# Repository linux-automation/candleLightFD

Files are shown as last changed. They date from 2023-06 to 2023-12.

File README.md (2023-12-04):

# candleLight FD

candleLight FD is a modern, CAN-FD capable version of the 
[candleLight](https://github.com/linux-automation/candleLight/) based on a STM32G0B1 microcontroller.

Out of the box it comes with a single CAN channel placed.
But footprints for a second CAN channel are available.

The candleLight FD is - like the candleLight - licensed under the CERN OHL v1.2 open hardware license.

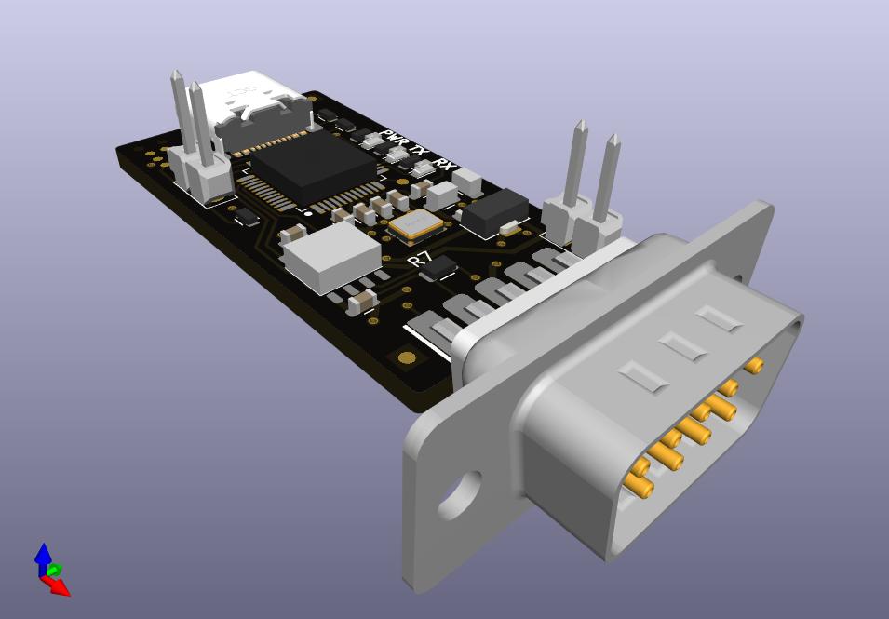
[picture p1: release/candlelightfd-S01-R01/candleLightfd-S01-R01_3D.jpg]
candleLight FD revision 1


## Where to get one

The candleLight FD is available from [Linux Automation](https://linux-automation.com)
as a SMD-assembled and functionally tested kit.

## Hardware

### Interfaces

The candleLight FD uses a USB-C (USB 2 only) connector to connect to your PC.

CAN is provided on the industry standard D-SUB9 pinout:

   * CAN1:
     * High: Pin 7
     * Low: Pin 2
   * CAN2:
     * High: Pin 8
     * Low: Pin 1
   * Power:
     * 12V: Pin 9 (can be provided via P1)
     * GND: Pin 3, Pin 6

### Releases: Revision 1

[Manufacturing Data](./release/candlelightfd-S01-R01) |
[Schematic](./release/candlelightfd-S01-R01/candlelightfd-S01-R01-V01/candlelightfd-S01-R01.pdf) |
[Interactive BOM](./release/candlelightfd-S01-R01/candlelightfd-S01-R01-V01/candlelightfd-S01-R01_BOM.html)

(This is the current release.)

Release Notes:

  * Initial release of the candleLight FD.

## Firmware

The firmware is based on the [candleLight_fw](https://github.com/candle-usb/candleLight_fw).
Select the board config `BOARD_candleLightFD` when building the firmware.

> **_NOTE_**: We are currently upstreaming our changes to the *candleLight_fw* repository.
> While doing so you can find our sources 
> [here](https://github.com/linux-automation/candleLight_fw/tree/topic/candleLightFD).

## Programming and Debugging

Everyday programming can be done via USB.
Simply invoke `dfu-util` while the device is running.
More information on flashing can be found in the
[firmware repository](https://github.com/candle-usb/candleLight_fw#flashing).

In case the device is bricked: Short the two pins labeled *BOOT* while powering on
the device.
The CPU will start in *serial download mode*.

For debugging a single wire interface is exposed on X3.
It can be connected using a [Tag Connect TC2030-IDC-NL](https://www.tag-connect.com/product/tc2030-idc-nl)
adapter.
The pinout is derived from the CandleLight.

The pinout is:

    * Pin 1: 3V3
    * Pin 2: SWCLK
    * Pin 3: GND
    * Pin 4: SWDIO
    * Pin 5: NRST
    * Pin 6: (not connected)

This picture shows X3 on the device.
X3 is the connector in the lower left corner - below the USB-C connector.

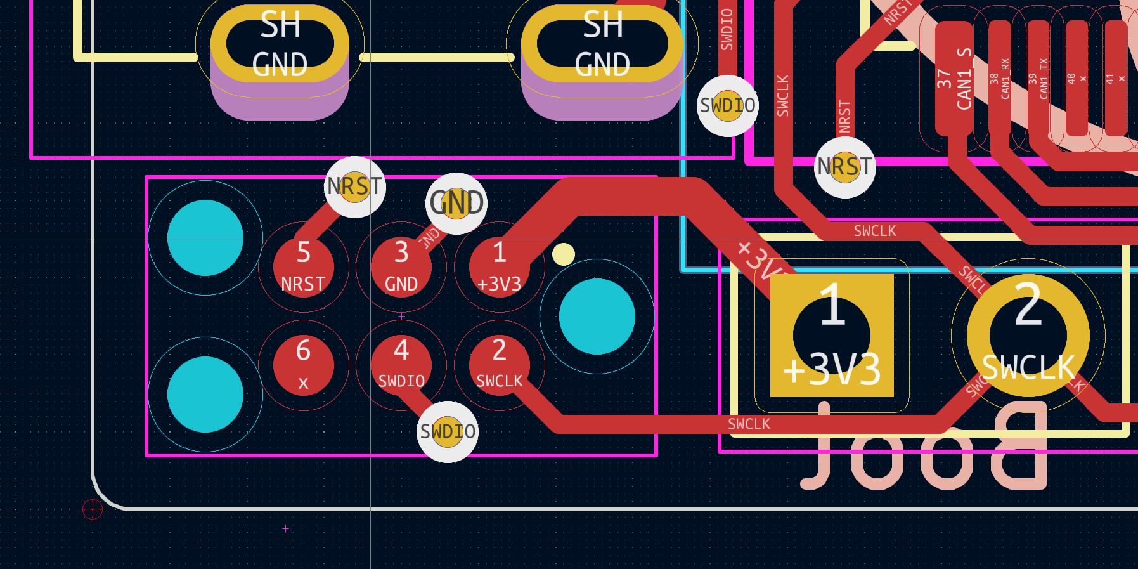
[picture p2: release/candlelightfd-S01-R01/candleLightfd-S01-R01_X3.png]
candleLight X3


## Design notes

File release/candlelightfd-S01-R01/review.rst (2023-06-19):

PCB / PCBA Review Checklists
============================

Schematic Related Topics
########################

Allgemeines
-----------

* [x] Braucht der Reset-Pin einen Pull-Up?
      Nein hat ein internen pullup von 40k.
* [x] Testpunkte für RX, TX, falls da genug Platz ist?

Drawing
-------

* [x] Are all sheets drawn with the same paper size? Is A4 used if possible?
* [x] Does the title block contain the name of the used git-repository?
* [x] Is the revision count in the title block up to date?
* [x] Are comments added where the schematic is not intuitive?

Nets and hierarchy
-------------------

* [x] Are all mayor nets named? (Either with a net label or due to the use of buses or hierarchical sheet entries.)
* [x] Are the directions of hierarchical sheet entries set in a meaningful way?

ERC
----

* [x] Does an ERC return errors? Are all severe error commented in the schematic?

Meta-Information
----------------

* [x] Do all symbols of manufacturer parts contain a "Manufacturer" and "MPN" field?
* [x] Are all libraries used from a local checkout of the kicad-ptx-lib or
      a projekt-local library? (Do not use absolute or system-wide paths.)

Electrical
----------

* [x] Do all Capacitors have a sufficient voltage derating applied?
      - Electrolyte Capacitors: U_R >= U_max * 1.3
      - Ceramic Capacitors:     U_R >= U_max * 1.5 .. 2
* [x] For all variants:
      * Are all necessary parts placed?
      * Are unnecessary parts not placed? (fit: none)
* [x] Are all analog devices (LDOs, OP-AMPs,...) within a stable operating region?
      * Check datasheet for stability region.
      * Check capacitive loads.
      * Check current to reference pins is sufficient
* [-] For designs including step-up/-down or flyback magnetics:
      are there footprints onto which snubber networks can be placed?
* [x] For designs containing digital high speed clock traces:
      are there footprints onto which filters can be placed?

PCB
####

General
-------

* [x] Does the PCB contain a PTXguin or a LAG rocket-penguin if the
      design is made for PTX or the LAG.
* [x] Does the PCB has a layer stackup in copper on every layer?
* [x] Is the PCB marked with the PCB number in copper on at least one side?
      Additional Marks in Mask or Silkscreen are possible.
      Marking must use variables to create the following names:
      * prefix
      * type_number
      * release
* [x] Does a DRC return no severe errors?
* [x] Are all libraries used from a local checkout of the kicad-ptx-lib or
      a projekt-local library? (Do not use absolute or system-wide paths.)
* [x] Have all changes been imported from the schematic?
* [x] Is the auxiliary origin reference point set to a corner of the PCB?
      Preferably on the metric grid.
      Preferably on the lower left corner of the PCB.

* [x] Is the layer stack in the drawing frame up to date?
      - All layers mentioned?
      - Copper thickness, impedances, finishes correct?

* [x] Are fiducials placed on all sides with SMD or THT components?
      Place at least 3 fiducials on each side.
      Does the fiducial match the manufacturers specifications?

* [-] Are planes split in a useful way?
      - Analog and digital parts are separated
      - High currents are directed away from sensitive circuits
      - Oscillators are placed on a GND-island
* [-] Are the reference planes of high-speed signals contiguous?
      Are planes AC-coupled where reference planes change?

* [-] Have impedance controlled traces been routed with the correct width/gap for the layer?
* [-] Is a definition of impedance controlled traces placed on a non-copper layer
      and is it up to date?

* [-] Are clearance and creepage requirements (for areas with high voltages)
      met?

Testing
#######

* [x] Is there a way to bring up the device at EOL or in maintenance?
      e.g. flash software, readout images, ...
      All signals needed to bring the device into non-normal
      boot-modes must be exposed to a connector or testpoint.
* [x] Is there a way to test all mayor functions at EOL?
* [-] Does the PCB have drillings for mounting on a testing rig?
* [-] Do all mayor nets have test points or vias without tenting?
* [-] Are all test points placed at least 2.54mm apart?

* [x] Are potentially noisy traces (e.g. unfiltered outputs of voltage
      regulators) only as wide as they have to be?
      Unnecessarily thick traces increase the coupling of noise onto
      planes and other traces.

Create release
##############

* [x] Have Vias been untented? (jma's KiCAD-plugin: https://gitlab.pengutronix.de/jma/kicad_plugins)
* [x] Have Planes been rebuilt? (use shortcut B in PCBNEW)

* [x] Change Status from Draft to Release
* [x] Create new folder in release
* [ ] Add release to release management (https://gitlab.pengutronix.de/hardware/release_management)

Manufacturing Data
##################

Directory structure is defined here:
  https://wiki.pengutronix.de/manual/devel/hardware/kicad-project.html

* [x] Call `release_generator.py <release_tag>`

* Assembly:
  * [x] Convert the -extended.bom.csv to .xlsx for manufacturing.

  * (-) Optional: List of BOM changes:
        * [-] Use tools/bom/bom_diff.sh prev-bom.csv cur-bom.csv | aha > bom-diff.html
              to generate a list of changes to the BOM between revisions.
        * [-] Sanity-Check the listed changes to the bom.

  * [x] Interactive HTML BOM:
        PCBNEW -> Interactive HTML BOM
        Settings:
        * Activate: "Incldue Tracks/zones"
        * Activate: "Include nets"

* PCB:
  * PCB Data as PDF:
    * Output into a directory like:
      ./release/name-S01-R01/name-P01-R01-V01/pdf/
    * PCBNEW -> File -> Plot
    * Settings:
      * Plot Format: Gerber
      * Active "Plot border and title block"
      * Deactivate "Exclude PCB edge from other layers"
      * Deactivate "Do not tent vias"
      * Activate "Check zone files before plotting"
      * Layers:
        * [x] Cu-Layers depending on Project
        * [x] Paste
        * [x] Silkscreen
        * [x] Mask
        * [x] Uwgs. User (if containing e.g. Size of PCB)
        * [x] Edge.Cuts
        * [x] Fab and CrtYrd -layer
  * 3D Render of PCB as JPG:
    * Output into a directory like:
      ./release/name-S01-R01/name-P01-R01-V01/
    * PCBNEW -> 3D-View -> File -> 'Export Current ciew as JPEG'
    * Settings:
      * Set Silk and Mask color according to layer stack
    * [x] One Render that shows the PCBA from TOP
    * [x] One Render that shows the PCBA from BOT
    * (x) Optionally: Renderings that show important details
  * [x] Test-Data for flying probe:
    * Output into a directory like:
      ./release/name-S01-R01/name-P01-R01-V01/cad/
    * \*.cad
    * In PCBNEW -> File -> Export -> GenCAD

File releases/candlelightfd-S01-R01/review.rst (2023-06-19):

PCB / PCBA Review Checklists
============================

Schematic Related Topics
########################

Allgemeines
-----------

* [x] Braucht der Reset-Pin einen Pull-Up?
      Nein hat ein internen pullup von 40k.
* [x] Testpunkte für RX, TX, falls da genug Platz ist?

Drawing
-------

* [x] Are all sheets drawn with the same paper size? Is A4 used if possible?
* [x] Does the title block contain the name of the used git-repository?
* [x] Is the revision count in the title block up to date?
* [x] Are comments added where the schematic is not intuitive?

Nets and hierarchy
-------------------

* [x] Are all mayor nets named? (Either with a net label or due to the use of buses or hierarchical sheet entries.)
* [x] Are the directions of hierarchical sheet entries set in a meaningful way?

ERC
----

* [x] Does an ERC return errors? Are all severe error commented in the schematic?

Meta-Information
----------------

* [x] Do all symbols of manufacturer parts contain a "Manufacturer" and "MPN" field?
* [x] Are all libraries used from a local checkout of the kicad-ptx-lib or
      a projekt-local library? (Do not use absolute or system-wide paths.)

Electrical
----------

* [x] Do all Capacitors have a sufficient voltage derating applied?
      - Electrolyte Capacitors: U_R >= U_max * 1.3
      - Ceramic Capacitors:     U_R >= U_max * 1.5 .. 2
* [x] For all variants:
      * Are all necessary parts placed?
      * Are unnecessary parts not placed? (fit: none)
* [x] Are all analog devices (LDOs, OP-AMPs,...) within a stable operating region?
      * Check datasheet for stability region.
      * Check capacitive loads.
      * Check current to reference pins is sufficient
* [-] For designs including step-up/-down or flyback magnetics:
      are there footprints onto which snubber networks can be placed?
* [x] For designs containing digital high speed clock traces:
      are there footprints onto which filters can be placed?

PCB
####

General
-------

* [x] Does the PCB contain a PTXguin or a LAG rocket-penguin if the
      design is made for PTX or the LAG.
* [x] Does the PCB has a layer stackup in copper on every layer?
* [x] Is the PCB marked with the PCB number in copper on at least one side?
      Additional Marks in Mask or Silkscreen are possible.
      Marking must use variables to create the following names:
      * prefix
      * type_number
      * release
* [x] Does a DRC return no severe errors?
* [x] Are all libraries used from a local checkout of the kicad-ptx-lib or
      a projekt-local library? (Do not use absolute or system-wide paths.)
* [x] Have all changes been imported from the schematic?
* [x] Is the auxiliary origin reference point set to a corner of the PCB?
      Preferably on the metric grid.
      Preferably on the lower left corner of the PCB.

* [x] Is the layer stack in the drawing frame up to date?
      - All layers mentioned?
      - Copper thickness, impedances, finishes correct?

* [x] Are fiducials placed on all sides with SMD or THT components?
      Place at least 3 fiducials on each side.
      Does the fiducial match the manufacturers specifications?

* [-] Are planes split in a useful way?
      - Analog and digital parts are separated
      - High currents are directed away from sensitive circuits
      - Oscillators are placed on a GND-island
* [-] Are the reference planes of high-speed signals contiguous?
      Are planes AC-coupled where reference planes change?

* [-] Have impedance controlled traces been routed with the correct width/gap for the layer?
* [-] Is a definition of impedance controlled traces placed on a non-copper layer
      and is it up to date?

* [-] Are clearance and creepage requirements (for areas with high voltages)
      met?

Testing
#######

* [x] Is there a way to bring up the device at EOL or in maintenance?
      e.g. flash software, readout images, ...
      All signals needed to bring the device into non-normal
      boot-modes must be exposed to a connector or testpoint.
* [x] Is there a way to test all mayor functions at EOL?
* [-] Does the PCB have drillings for mounting on a testing rig?
* [-] Do all mayor nets have test points or vias without tenting?
* [-] Are all test points placed at least 2.54mm apart?

* [x] Are potentially noisy traces (e.g. unfiltered outputs of voltage
      regulators) only as wide as they have to be?
      Unnecessarily thick traces increase the coupling of noise onto
      planes and other traces.

Create release
##############

* [ ] Have Vias been untented? (jma's KiCAD-plugin: https://gitlab.pengutronix.de/jma/kicad_plugins)
* [ ] Have Planes been rebuilt? (use shortcut B in PCBNEW)

* [ ] Change Status from Draft to Release
* [ ] Create new folder in release
* [ ] Add release to release management (https://gitlab.pengutronix.de/hardware/release_management)

Manufacturing Data
##################

Directory structure is defined here:
  https://wiki.pengutronix.de/manual/devel/hardware/kicad-project.html

* [ ] Call `release_generator.py <release_tag>`

* Assembly:
  * [ ] Convert the -extended.bom.csv to .xlsx for manufacturing.

  * ( ) Optional: List of BOM changes:
        * [ ] Use tools/bom/bom_diff.sh prev-bom.csv cur-bom.csv | aha > bom-diff.html
              to generate a list of changes to the BOM between revisions.
        * [ ] Sanity-Check the listed changes to the bom.

  * [ ] Interactive HTML BOM:
        PCBNEW -> Interactive HTML BOM
        Settings:
        * Activate: "Incldue Tracks/zones"
        * Activate: "Include nets"

* PCB:
  * PCB Data as PDF:
    * Output into a directory like:
      ./release/name-S01-R01/name-P01-R01-V01/pdf/
    * PCBNEW -> File -> Plot
    * Settings:
      * Plot Format: Gerber
      * Active "Plot border and title block"
      * Deactivate "Exclude PCB edge from other layers"
      * Deactivate "Do not tent vias"
      * Activate "Check zone files before plotting"
      * Layers:
        * [ ] Cu-Layers depending on Project
        * [ ] Paste
        * [ ] Silkscreen
        * [ ] Mask
        * [ ] Uwgs. User (if containing e.g. Size of PCB)
        * [ ] Edge.Cuts
        * [ ] Fab and CrtYrd -layer
  * 3D Render of PCB as JPG:
    * Output into a directory like:
      ./release/name-S01-R01/name-P01-R01-V01/
    * PCBNEW -> 3D-View -> File -> 'Export Current ciew as JPEG'
    * Settings:
      * Set Silk and Mask color according to layer stack
    * [ ] One Render that shows the PCBA from TOP
    * [ ] One Render that shows the PCBA from BOT
    * ( ) Optionally: Renderings that show important details
  * [ ] Test-Data for flying probe:
    * Output into a directory like:
      ./release/name-S01-R01/name-P01-R01-V01/cad/
    * \*.cad
    * In PCBNEW -> File -> Export -> GenCAD

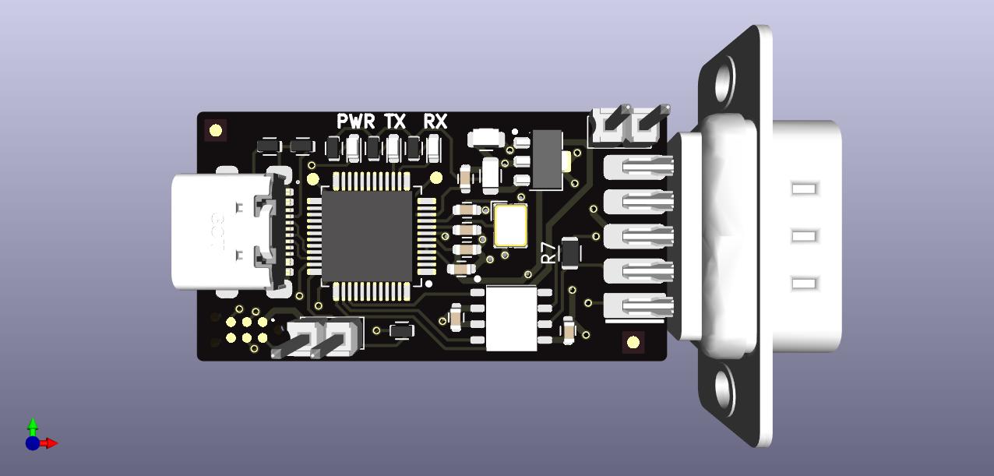
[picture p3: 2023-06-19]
release/candlelightfd-S01-R01/candleLightfd-S01-R01_Front.jpg

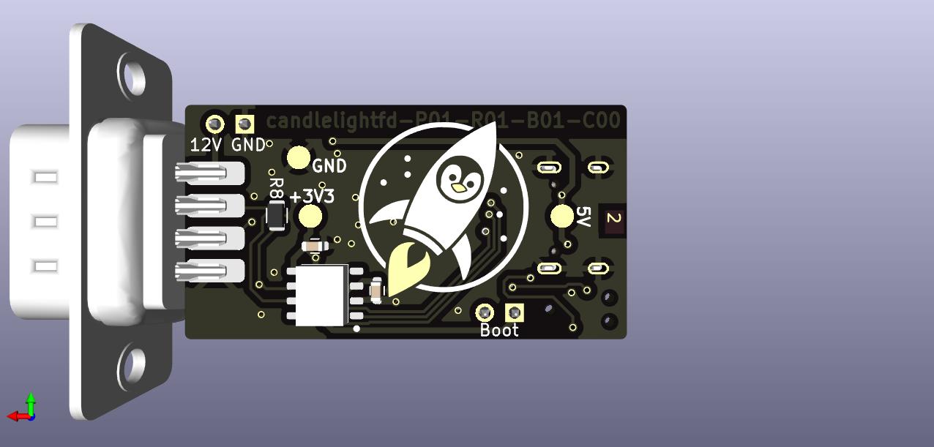
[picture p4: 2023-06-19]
release/candlelightfd-S01-R01/candleLightfd-S01-R01_Back.jpg

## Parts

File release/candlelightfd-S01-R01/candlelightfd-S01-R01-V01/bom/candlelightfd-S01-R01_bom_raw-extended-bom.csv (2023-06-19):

Company: Linux Automation GmbH
PCBA-Name: candleLightfd-S01.kicad_sch
PCBA-Revision: R01
Placement-Version: 01
PCBA-Title: Candlelight FD
Release-State: release
Release-Date: 2023-06-16
count | reference | manufacturer | mpn | value | description | capratedvoltage | color | datasheet | datasheet2 | displayname | displayvalue | fit | footprint | libref | libsource | package | state | tool
2.0 | C10, C8 | any | any | 100n_0603_X7R_10%_50V_-40C..125C_Chip-Capacitor | 100n, 0603, X7R, 10%, 50V, -40C .. 125C, Chip Capacitor | 50V | nan | nan, nan | nan, nan | nan, nan | 100n | all, fit: | Capacitors_SMD:C_0603 | C | Cap_10Percent_E24_0603_X7R_50V_-40C-125C:100n_0603_X7R_10%_50V_-40C..125C_Chip-Capacitor | 0603 | legacy | nan, nan
2.0 | C7, C6 | any | any | 10u_0805_X7R_10%_10V_-40C..125C_Chip-Capacitor | 10u, 0805, X7R, 10%, 10V, -40C .. 125C, Chip Capacitor | 10V | nan | nan, nan | nan, nan | nan, nan | 10u | all, fit: | Capacitors_SMD:C_0805 | C | Cap_10Percent_E24_0805_X7R_X7S_multipleV_-40C-125C:10u_0805_X7R_10%_10V_-40C..125C_Chip-Capacitor | 0805 | legacy | nan, nan
2.0 | C2, C1 | any | any | 6p2_0603_C0G_5%_50V_-40C..125C_Chip-Capacitor | 6p2, 0603, C0G, 5%, 50V, -40C .. 125C, Chip Capacitor | 50V | nan | nan, nan | nan, nan | nan, nan | 6p2 | all, fit: | Capacitors_SMD:C_0603 | C | Cap_5Percent_E24_0603_C0G_50V_-40C-125C:6p2_0603_C0G_5%_50V_-40C..125C_Chip-Capacitor | 0603 | legacy | nan, nan
1.0 | D3 | Kingbright | KPT-1608EC | KPT-1608EC | 0603, LED, red, 20mA, 2.0V, 15mcd, 150° | nan, nan | red | $PTX_DATASHEETS/datasheets/LED/Kingbright_KPT-1608EC.pdf | nan, nan | nan, nan | nan, nan | all, fit: | LEDs_Kingbright:LED_Kingbright_0603 | D | Kingbright:KPT-1608EC | 0603 | reviewed | nan, nan
2.0 | D2, D1 | Kingbright | KPT-1608SGC | KPT-1608SGC | 0603, LED, green, 20mA, 2.2V, 12mcd, 120° | nan, nan | green | $PTX_DATASHEETS/datasheets/LED/Kingbright_KPT-1608SGC.pdf | nan, nan | nan, nan | nan, nan | all, fit: | LEDs_Kingbright:LED_Kingbright_0603 | D | Kingbright:KPT-1608SGC | 0603 | reviewed | nan, nan
1.0 | R6 | any | any | 10k_0603_100mW_1%_E24_Chip-Resistor | 10k, 0603, 100mW, 1%, E24, Chip Resistor | nan, nan | nan | nan, nan | nan, nan | nan, nan | 10k | all, fit: | Resistors_SMD:R_0603 | R | Res_1Percent_E24_0603_100mW_-40C-90C:10k_0603_100mW_1%_E24_Chip-Resistor | 0603 | legacy | nan, nan
3.0 | R4, R3, R5 | any | any | 1k_0603_100mW_1%_E24_Chip-Resistor | 1k, 0603, 100mW, 1%, E24, Chip Resistor | nan, nan | nan | nan, nan | nan, nan | nan, nan | 1k | all, fit: | Resistors_SMD:R_0603 | R | Res_1Percent_E24_0603_100mW_-40C-90C:1k_0603_100mW_1%_E24_Chip-Resistor | 0603 | legacy | nan, nan
2.0 | R2, R1 | any | any | 5k1_0603_100mW_1%_E24_Chip-Resistor | 5k1, 0603, 100mW, 1%, E24, Chip Resistor | nan, nan | nan | nan, nan | nan, nan | nan, nan | 5k1 | all, fit: | Resistors_SMD:R_0603 | R | Res_1Percent_E24_0603_100mW_-40C-90C:5k1_0603_100mW_1%_E24_Chip-Resistor | 0603 | legacy | nan, nan
1.0 | U1 | ST | STM32G0B1CBT | STM32G0B1CBT | Cortex-M0+, ROM: 128KB, RAM: 144KB, USB, CAN-FD, SPI, I2C, USART, 44 GPIOs | nan, nan | nan | $PTX_DATASHEETS/datasheets/Microcontroller/STW_stm32g0b1re.pdf | $PTX_DATASHEETS/datasheets/Microcontroller/STW_stm32g0b1re_reference_maual.pdf | nan, nan | nan, nan | all, fit: | QFP:LQFP-48_7mmx7mm_Pitch0.5mm | U | ST:STM32G0B1CBT | LQFP48 | reviewed | nan, nan
1.0 | X2 | nan, nan | nan, nan | nan, ~ |  | nan, nan | nan | nan, nan | nan, nan | nan, nan | nan, nan | nan, all | d-sub:D-SUB-9_side | X | d-sub:D-SUB-9_side | nan, nan | nan, nan | nan, nan
1.0 | U2 | Microchip | MCP1754ST-3302E/MB | MCP1754ST-3302E/MB | Single LDO, 3.3V, 150mA, 16V, SOT-89, Low Power, -40 .. 150°C, MUYYWW | nan, nan | nan | $PTX_DATASHEETS/datasheets/PowerSupply/Microchip_MCP1754-MCP1754S_LDO.pdf | nan, nan | nan, nan | nan, nan | all, fit: | TO_SMD:SOT-89 | U | microchip:MCP1754ST-3302E/MB | SOT-89 | reviewed | nan, nan
3.0 | C4, C3, C5 | Multicomp | MC0603B104K500CT | 100n | 100nF, 50V, 10%, X7R, 0603, MLCC, Multicomp | nan, nan | nan | http://www.farnell.com/datasheets/1901289.pdf | nan, nan | nan, nan | nan, nan | all, fit: | Capacitors_SMD:C_0603 | C | multicomp:100n | 0603 | legacy | nan, nan
1.0 | U3 | NXP | TJA1051T/3 | TJA1051T3 | High-speed CAN transceiver, Dual 3,3V / 5V voltage inputs, SO-8 Package | nan, nan | nan | $PTX_DATASHEETS/datasheets/CAN/NXP-TJA1051-rev09.pdf | nan, nan | nan, nan | nan, nan | all, fit: | tssop:SOIC-8_3.90mmx4.90mm_Pitch1.27mm | U | nxp:TJA1051T3 | SOIC-8_3.90mmx4.90mm_Pitch1.27mm | reviewed | nan, nan
1.0 | X3 | Tag-Connect | TC2030-NL | TC2030-NL | 6-Pin Tag Connect Connector Area [No-BOM] | nan, nan | nan | $PTX_DATASHEETS/datasheets/Connectors/Tag-Connect_TC2030-IDC-NL-Datasheet-Rev-B.pdf | nan, nan | nan, nan | nan, nan | all, fit: | Connector_Tag-Connect:TC2030-NL | X | tag-connect:TC2030-NL | mfg-specific 6-pin | reviewed | nan, nan
1.0 | X1 | Würth Elektronik | 629722000214 | 629722000214_pasteInHole | 16-Pin, USB-C, Type C, USB 2.0, 0.8mm PCB, SMD, 5A, Paste in hole | nan, nan | nan | $PTX_DATASHEETS/datasheets/Connectors/Wuerth_629722000214_USB-C_2.0_16Pin.pdf | nan, nan | nan, nan | nan, nan | all, fit: | Socket_GCT:USB4105_pasteInHole | X | wuerth:629722000214_pasteInHole | SMD mfg-specific | reviewed | None
1.0 | Y1 | Würth Elektronik | 830108313809 | 830055299, 830108313809 | 8MHz, Quarz, 30ppm, CL=12pF, 4Pin SMD 3.2mm x 2.5mm, -40°C ...85°C, LFXTAL083138RL3K | nan, nan | nan | $PTX_DATASHEETS/datasheets/Crystal/WE_830108313809_8MHz.pdf | nan, nan | 8MHz | nan, nan | all, fit: | crystal:Crystal_4Pin_SMD_3.2mmx2.5mm | Y | wuerth:830108313809 | SMD 4Pin Crystal 3.2mm | reviewed | nan, nan
7.0 | C11, C9, P1, P2, R7, R8, U4 | DO NOT PLACE

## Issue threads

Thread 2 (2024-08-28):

CanFD ：Operation not supported

L-SY, 2024-08-28:
I designed a PCB board based on your open-source design and flashed the candleLightFD.bin firmware onto it.
When I plug it into my Ubuntu system, it recognizes the CAN device:
```
ip -details link show can0
12: can0: <NOARP,ECHO> mtu 16 qdisc noop state DOWN mode DEFAULT group default qlen 10
    link/can  promiscuity 0 minmtu 0 maxmtu 0
    can state STOPPED restart-ms 0
	  bitrate 1000000 sample-point 0.750
	  tq 25 prop-seg 14 phase-seg1 15 phase-seg2 10 sjw 1
	  gs_usb: tseg1 1..256 tseg2 1..128 sjw 1..128 brp 1..512 brp-inc 1
	  clock 40000000 numtxqueues 1 numrxqueues 1 gso_max_size 65536 gso_max_segs 65535
```
but I am unable to use CAN FD. I encounter the error RTNETLINK answers:
```
Operation not supported when running sudo ip link set can0 up type can bitrate 1000000 dbitrate 1000000 fd on.
RTNETLINK answers: Operation not supported
```

How to solve this err
Looking forward to hearing from you！

FuzzyPt233, 2024-12-20:
Hi there! Can you please share the 'candleLightFD.bin' to me to test on my board? I do not have the develop environment on Linux so that haven't test my board.

SmithChart, 2025-01-07:
Hi @FuzzyPt233 ,

> Hi there! Can you please share the 'candleLightFD.bin' to me to test on my board? I do not have the develop environment on Linux so that haven't test my board.

we are currently shipping a fork of the upstream. We are working on mainlining - but that is still ongoing.
I've added links and the binary to our product page here:
https://linux-automation.com/en/products/candlelight-fd.html

SmithChart, 2025-01-07:
Hi @L-SY,

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

I am sorry. I must have missed your issue. Which firmware binary did you use? Did you compile from source? Based on which commit? What Linux version are you on?

ascitegong, 2025-06-11:
I encounterred the same issue.

```
$ sudo ip -details link show can1
228: can1: <NOARP,ECHO> mtu 16 qdisc pfifo_fast state DOWN mode DEFAULT group default qlen 10
    link/can  promiscuity 0 minmtu 0 maxmtu 0
    can state STOPPED restart-ms 100
          bitrate 500000 sample-point 0.875
          tq 25 prop-seg 34 phase-seg1 35 phase-seg2 10 sjw 1
          gs_usb: tseg1 1..256 tseg2 1..128 sjw 1..128 brp 1..512 brp-inc 1
          clock 40000000 numtxqueues 1 numrxqueues 1 gso_max_size 65536 gso_max_segs 65535

$ sudo ip link set can1 up type can bitrate 500000 dbitrate 2000000 fd on
RTNETLINK answers: Operation not supported
```

I'm using Ubuntu20.04, with kernel 5.15.
BTW, the device was correctly recognized as candlelightFD
```
$ lsusb
Bus 002 Device 001: ID 1d6b:0003 Linux Foundation 3.0 root hub
Bus 001 Device 066: ID 1d50:606f OpenMoko, Inc. candleLightFD gs_usb
Bus 001 Device 067: ID 0c72:0012 PEAK System PCAN-USB FD
Bus 001 Device 001: ID 1d6b:0002 Linux Foundation 2.0 root hub
```

ascitegong, 2025-06-11:
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

Problem resolved by upgrading Linux kernel. Kernel version should be >= 5.18
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

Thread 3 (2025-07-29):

Why the pinout of CAN2 on DB9?

Cushychicken, 2025-07-29:
Good morning!

Writing to ask about why your team chose the DE-9 pinout they did for the CAN2 lanes.

CAN1 and power connections on this board both make sense to me - these match the CIA-106 spec for CAN over a DE-9 connector:

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

I'm not certain what informed the choice for CAN2's pinout on the DE-9 connector.

Is there some ancillary standard for CAN over DE-9 that I am not aware of?

Not an issue per se - I'm just curious in learning the reasoning behind this decision.

I love your product and I count myself among one of your happy customers. 👍 😄

SmithChart, 2025-07-31:
Hi @Cushychicken,

our pinout for the 2nd channel is used by the automotive industry. You can, for example, buy devices and cables from Vector using this pinout: https://cdn.vector.com/cms/content/products/Hardware_Accessory/graphics/Cables_Adapters/CANcable_2Y.jpg
While researching possible pinouts we also found automation devices using this definition. But I cant find the references online anymore.

So it's not a standard. Just a convenient pinout that *shout not* collide with the existing CIA-106 definition 😄

Closed 2025-07-31.

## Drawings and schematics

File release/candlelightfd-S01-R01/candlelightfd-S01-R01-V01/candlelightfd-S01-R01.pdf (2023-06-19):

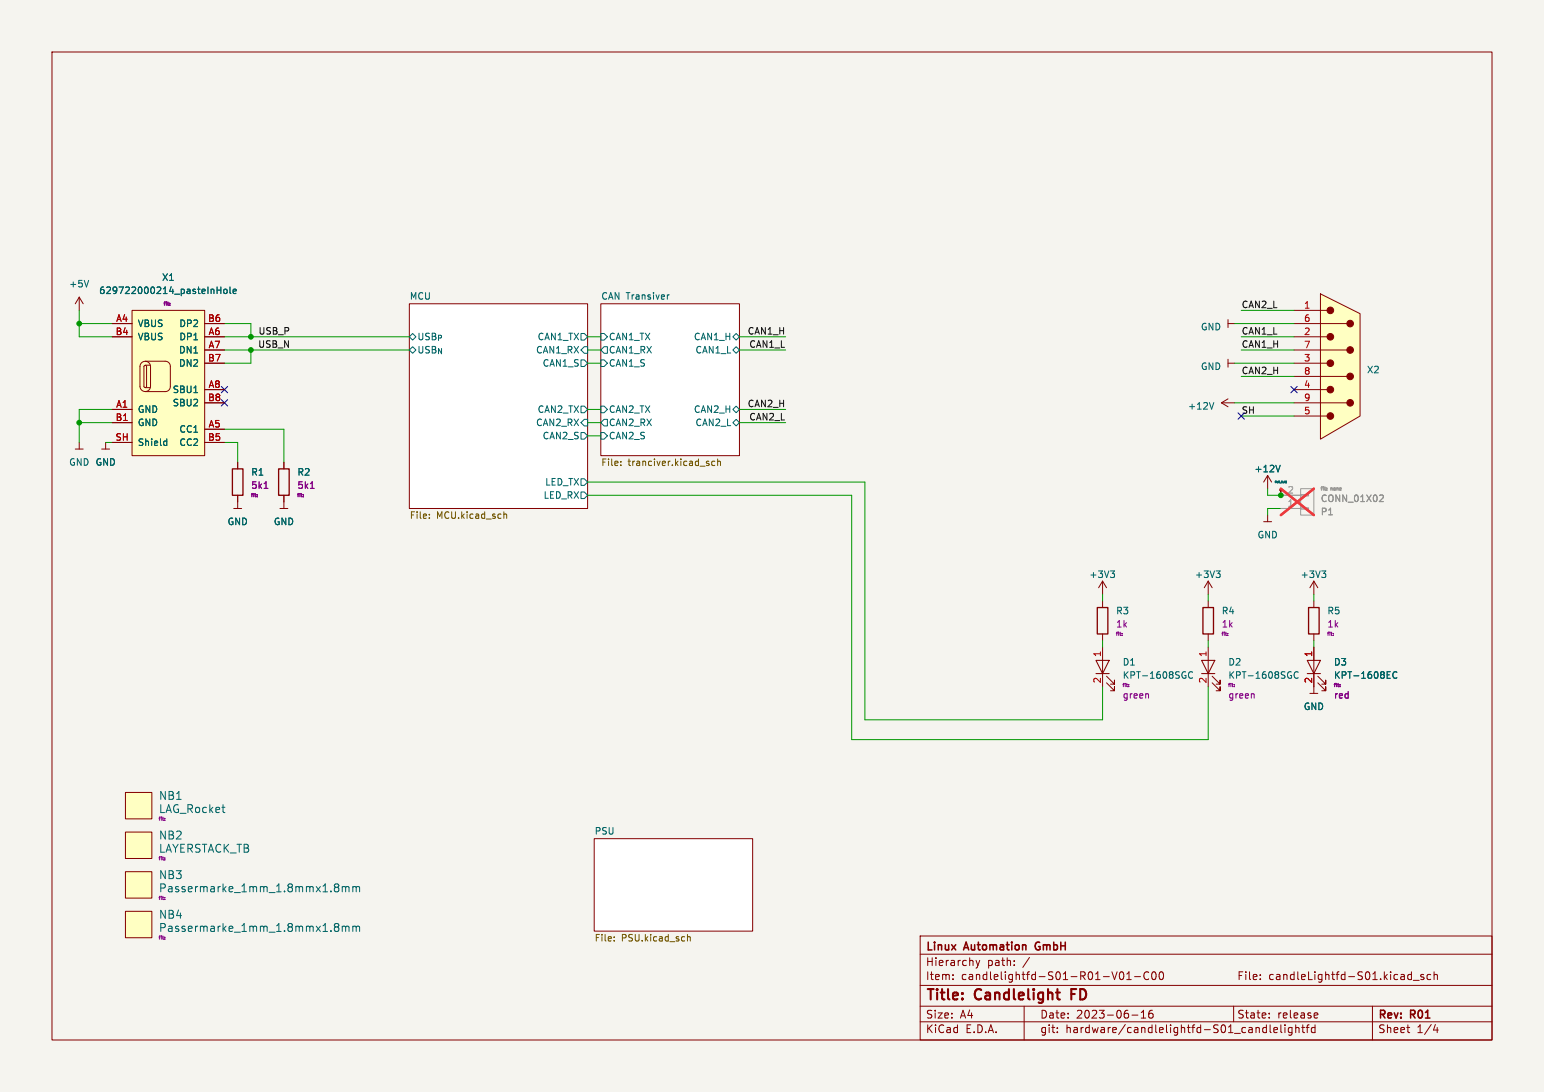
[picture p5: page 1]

CAN2_L CAN2_TX CAN2_RX CAN2_S CAN1_RX CAN1_TX CAN1_S CAN Transiver File: tranciver.kicad_sch USB_{N}

git: hardware/candlelightfd-S01_candlelightfd State: release
Date: 2023-06-16

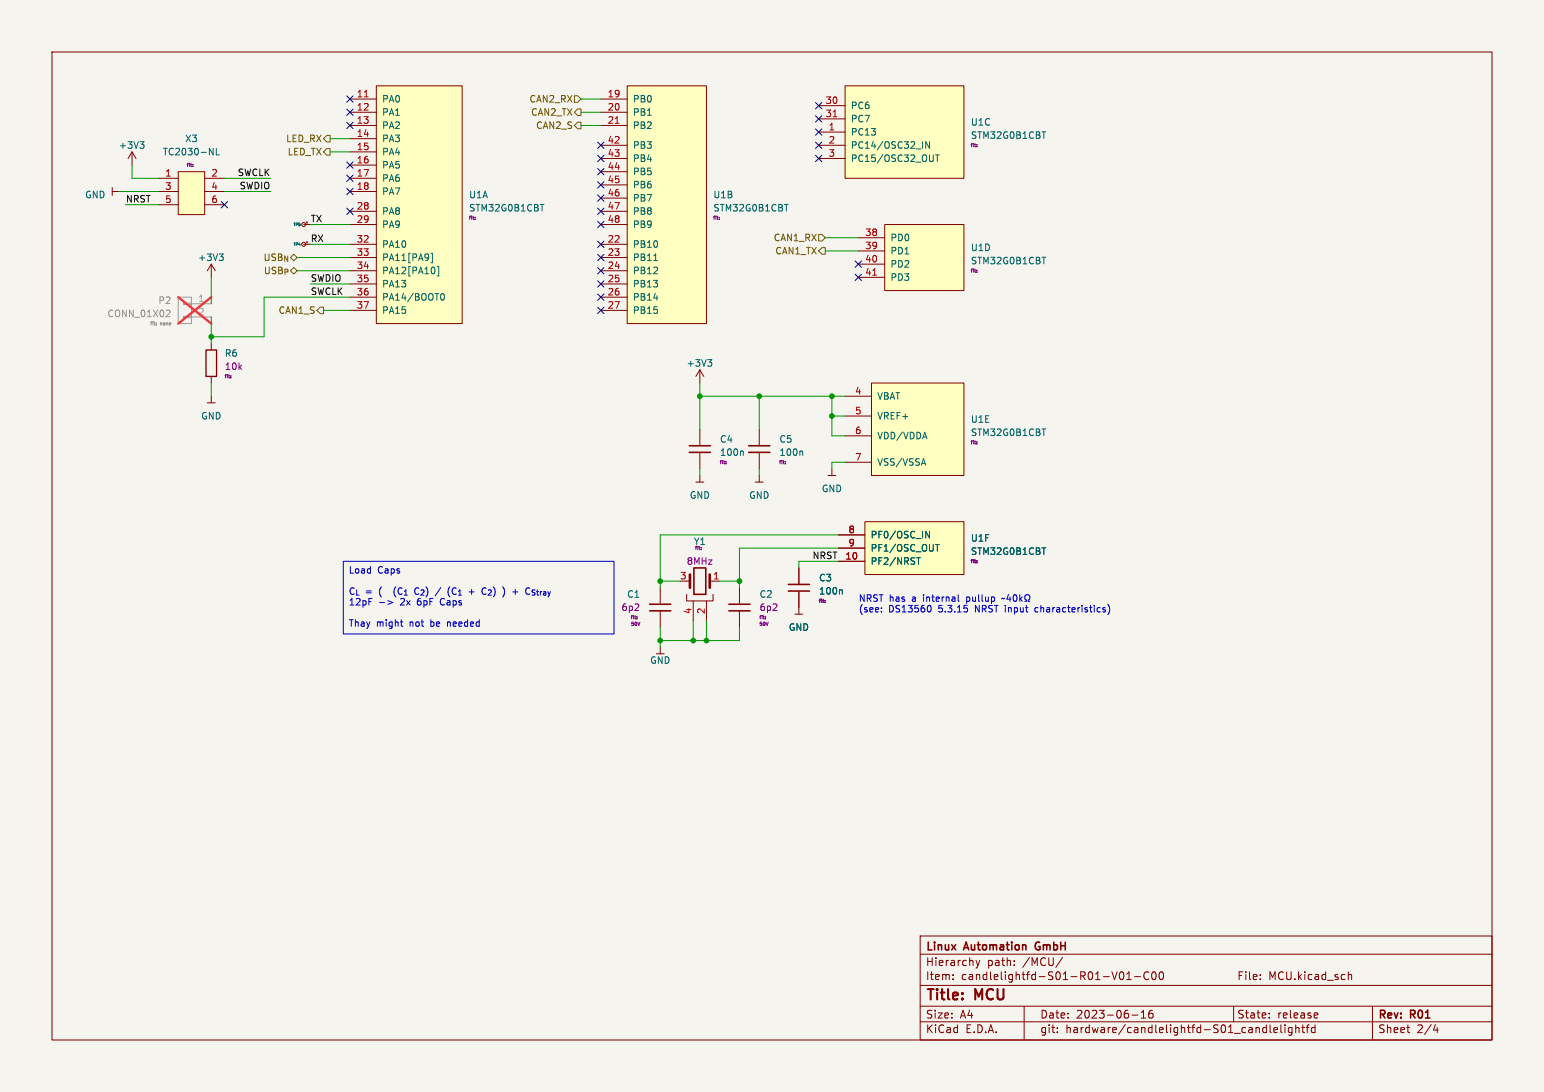
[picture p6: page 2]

(see: DS13560 5.3.15 NRST input characteristics) Load Caps

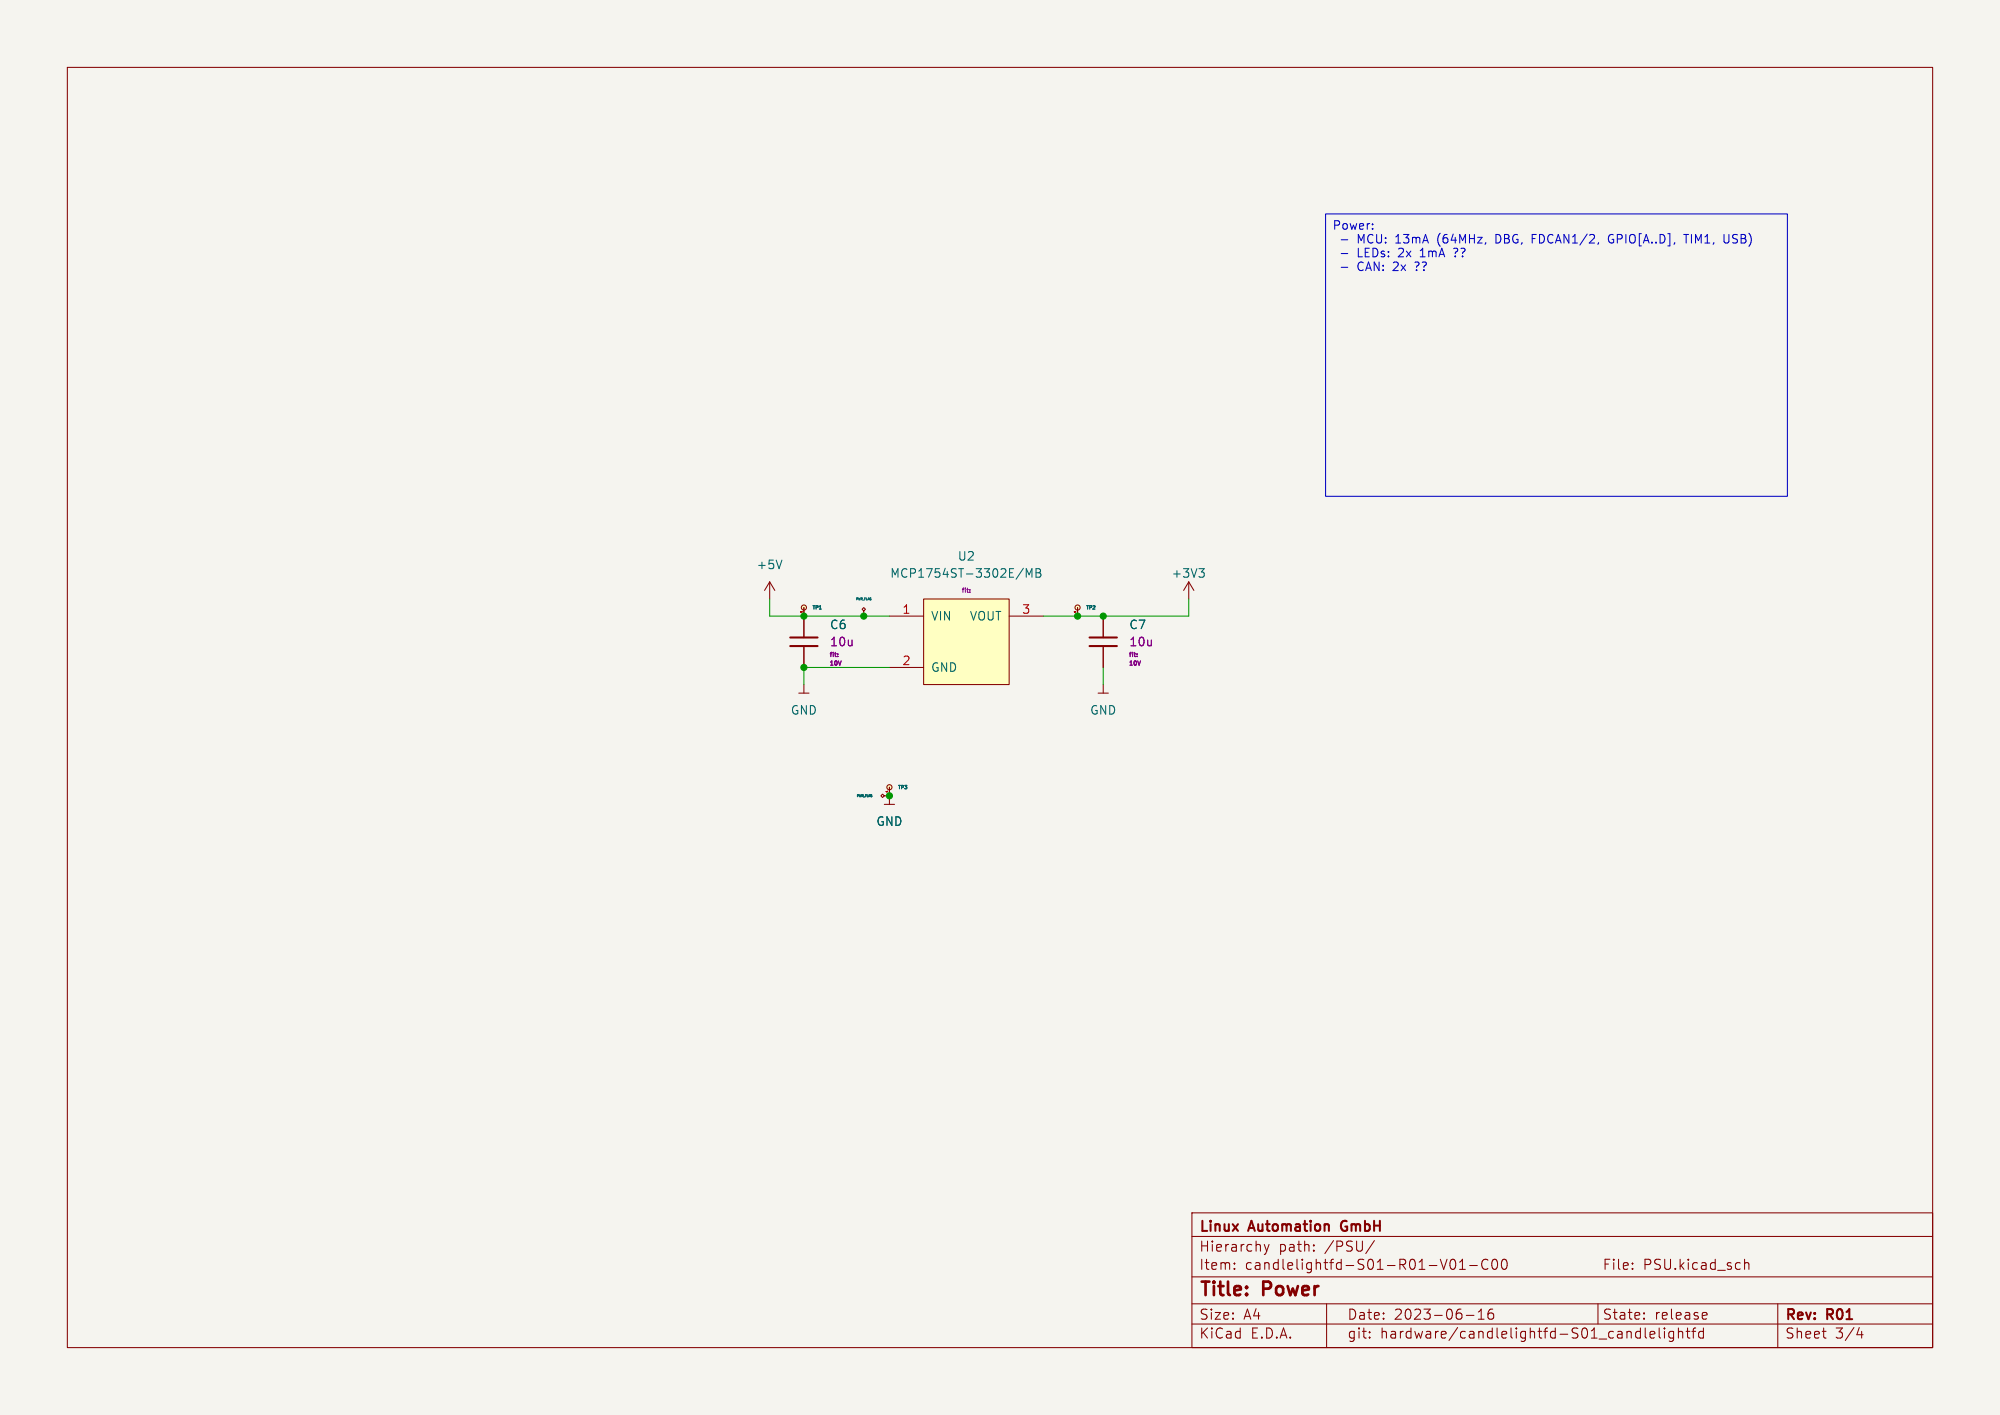
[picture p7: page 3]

Power: - MCU: 13mA (64MHz, DBG, FDCAN1/2, GPIO[A..D], TIM1, USB)

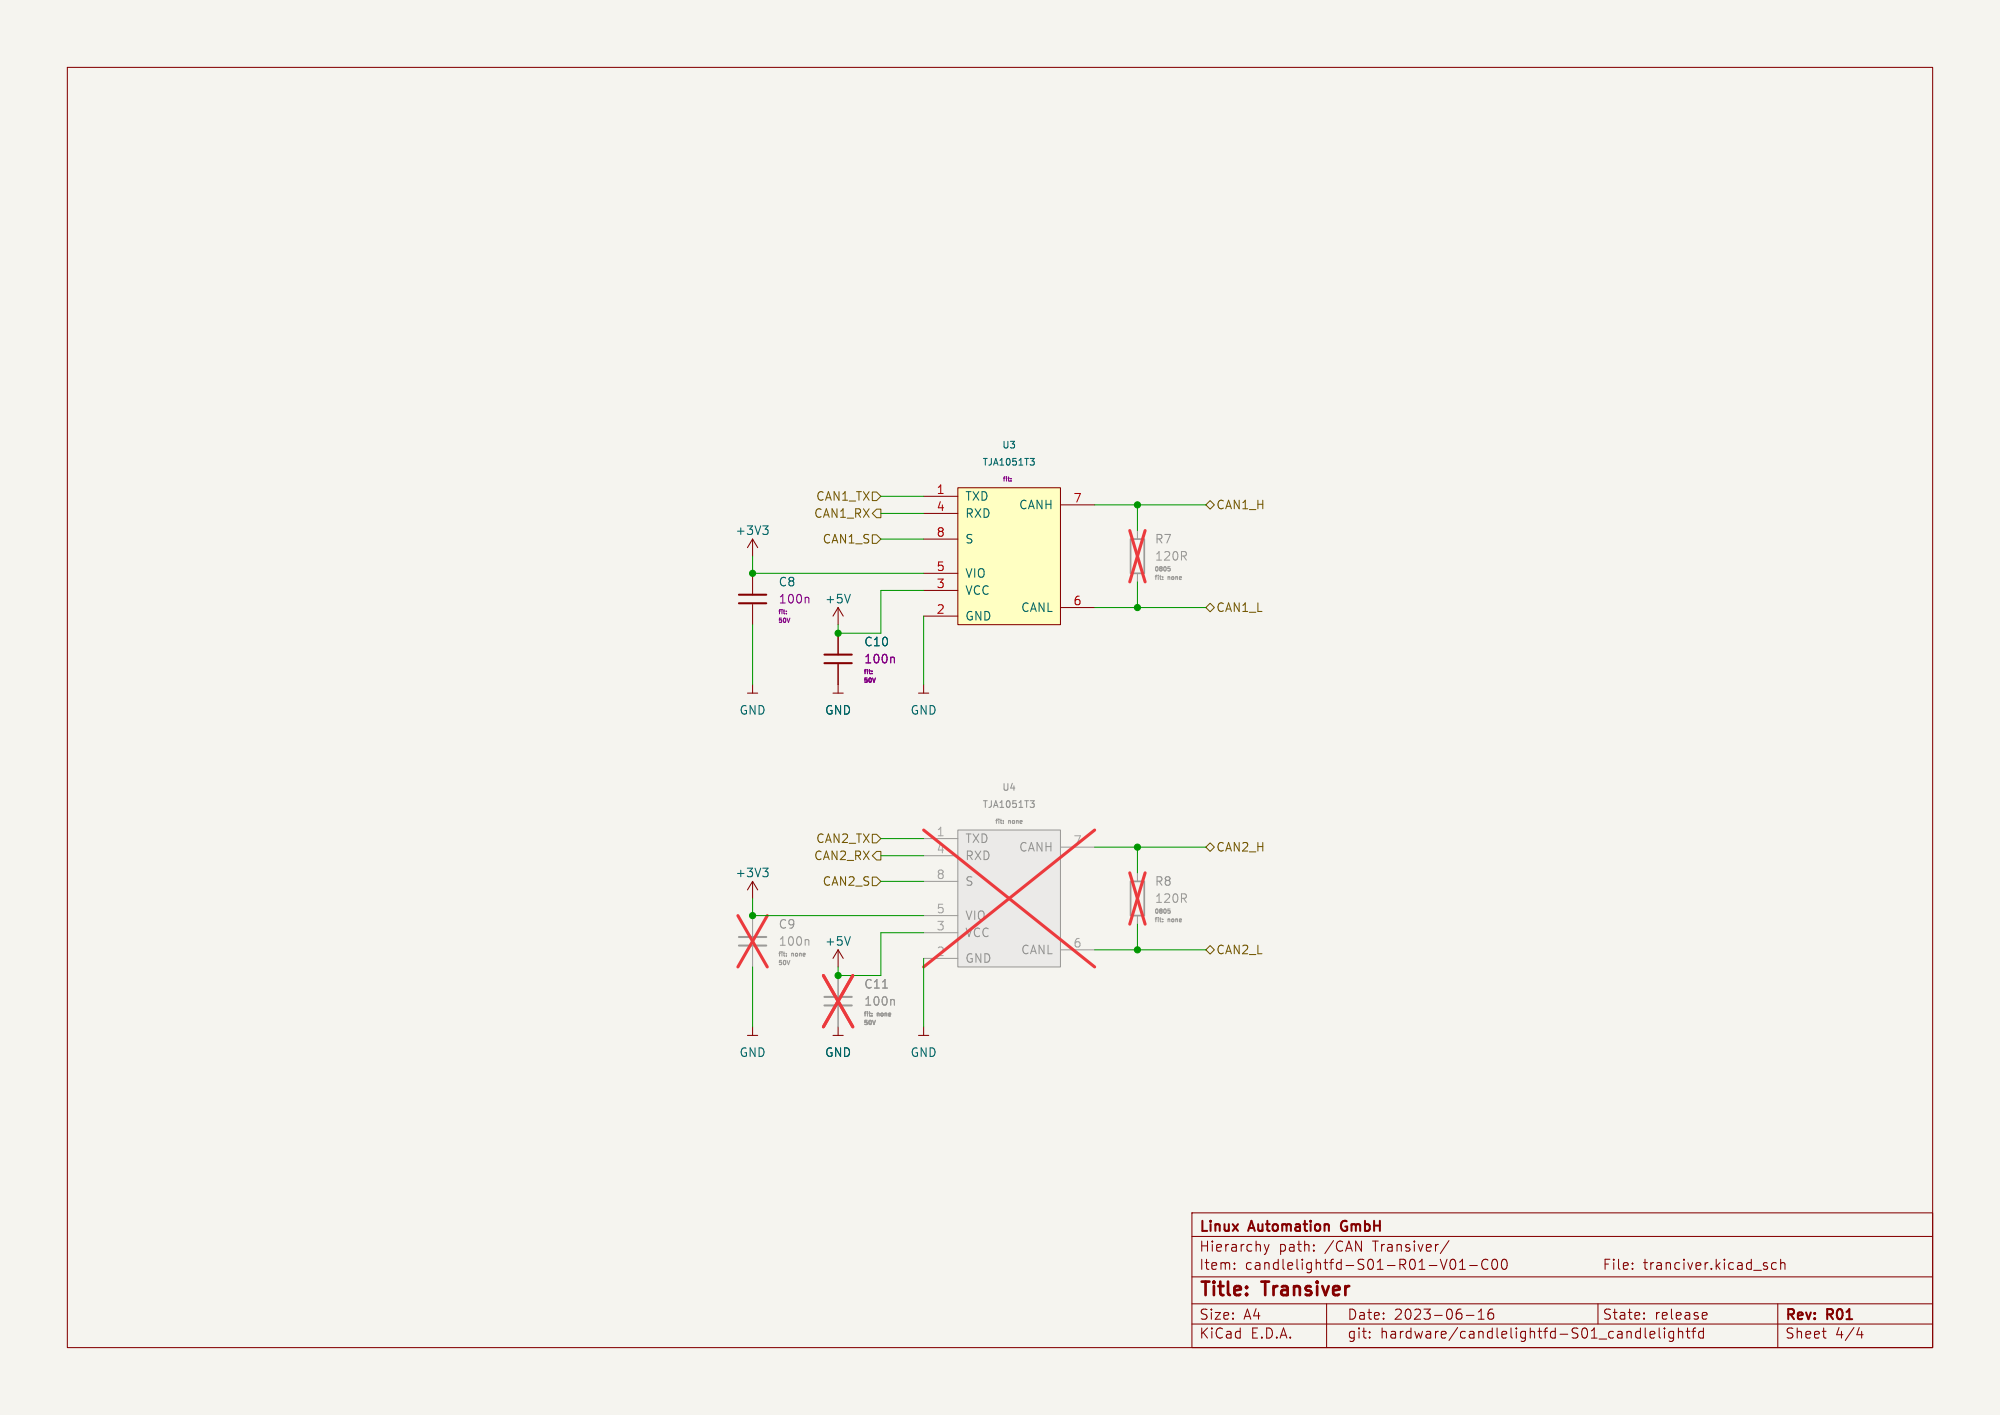
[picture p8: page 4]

fit: none
git: hardware/candlelightfd-S01_candlelightfd State: release GND

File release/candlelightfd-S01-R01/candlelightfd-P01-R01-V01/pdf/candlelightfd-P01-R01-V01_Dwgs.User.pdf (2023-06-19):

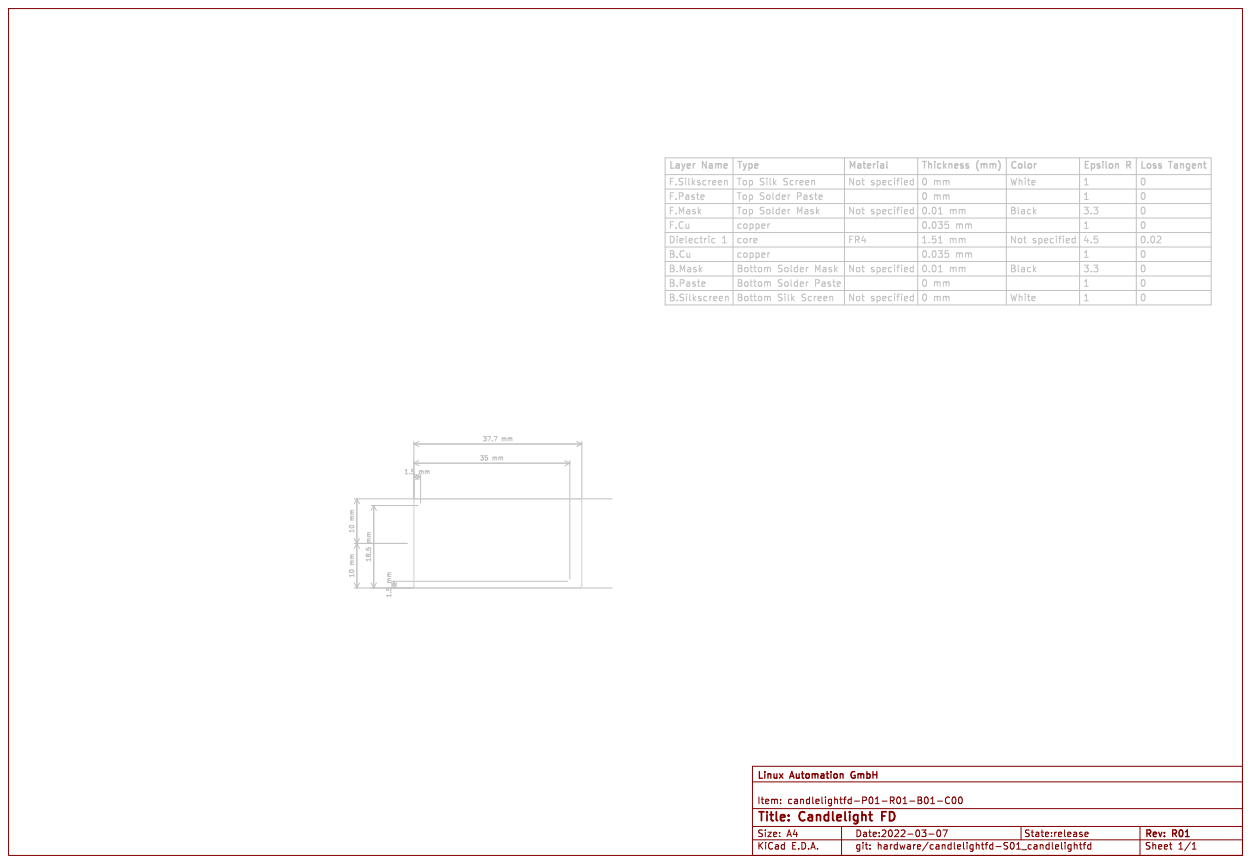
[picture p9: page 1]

F.Paste | | Top Solder Mask | | | | | | | Thickness | (mm) | Color B.Silkscreen B.Paste Not specified | Epsilon R 3.3

Type Bottom Solder Mask Top Silk | | Screen | | Not specified | 0 mm | | 1

0 mm | | | | Loss Tangent 0.035 mm

copper core | | 0 mm 1.51 | mm | | | 4.5 | 0 0.02

White | 1 | 0 Not specified

git: hardware/candlelightfd-S01_candlelightfd State:release
Date:2022-03-07

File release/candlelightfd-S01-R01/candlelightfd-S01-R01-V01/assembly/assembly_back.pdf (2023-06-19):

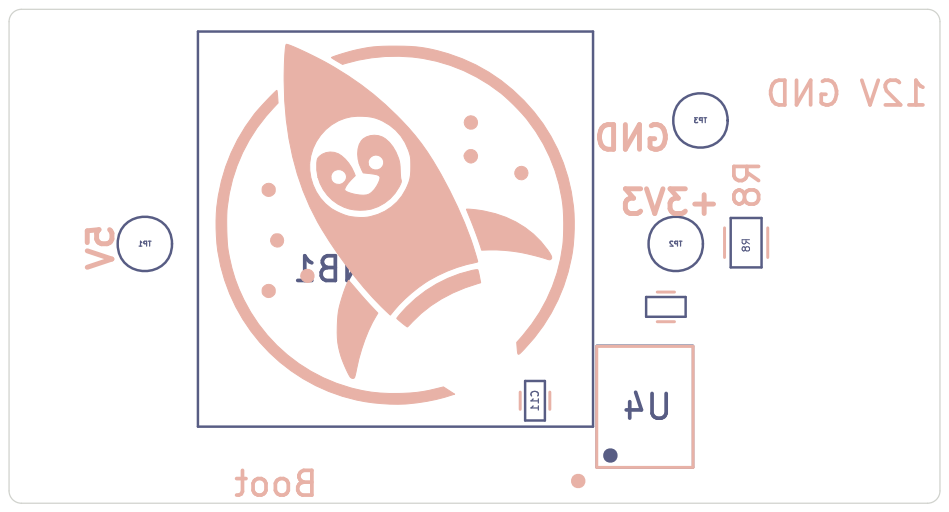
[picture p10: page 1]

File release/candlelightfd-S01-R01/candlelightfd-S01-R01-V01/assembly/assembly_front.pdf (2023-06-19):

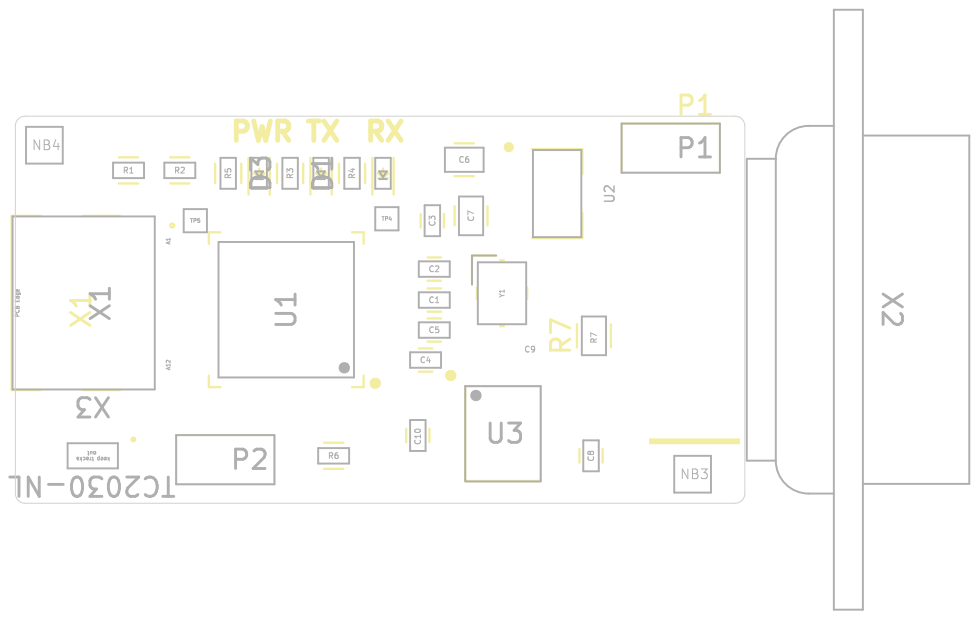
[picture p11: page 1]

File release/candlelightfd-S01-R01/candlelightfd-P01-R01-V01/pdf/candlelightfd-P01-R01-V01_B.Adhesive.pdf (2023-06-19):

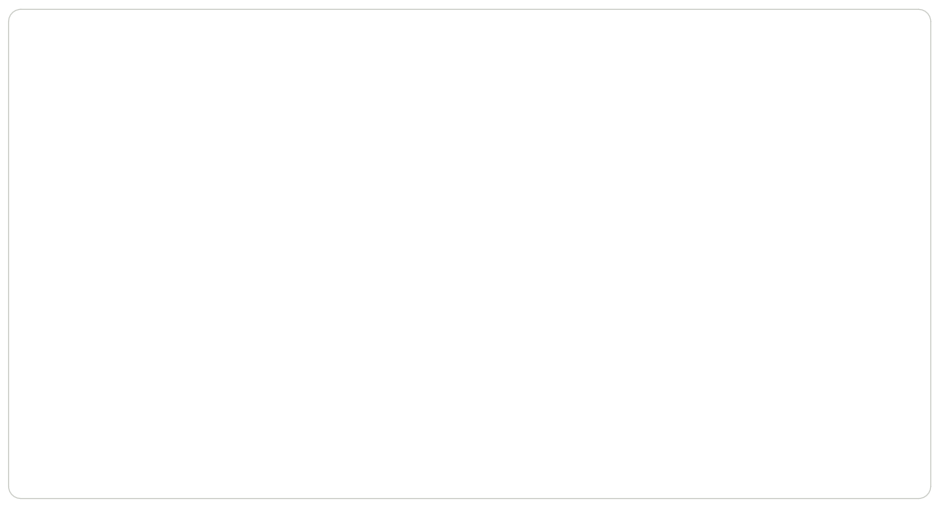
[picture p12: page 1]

git: hardware/candlelightfd-S01_candlelightfd State:release
Date:2022-03-07

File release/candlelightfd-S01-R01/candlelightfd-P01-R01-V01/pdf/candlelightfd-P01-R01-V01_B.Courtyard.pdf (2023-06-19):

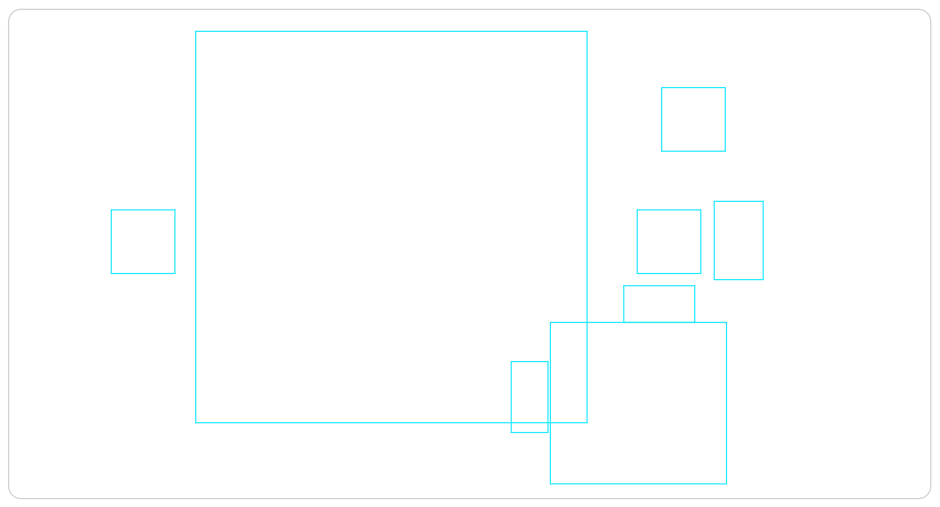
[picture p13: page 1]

git: hardware/candlelightfd-S01_candlelightfd State:release
Date:2022-03-07

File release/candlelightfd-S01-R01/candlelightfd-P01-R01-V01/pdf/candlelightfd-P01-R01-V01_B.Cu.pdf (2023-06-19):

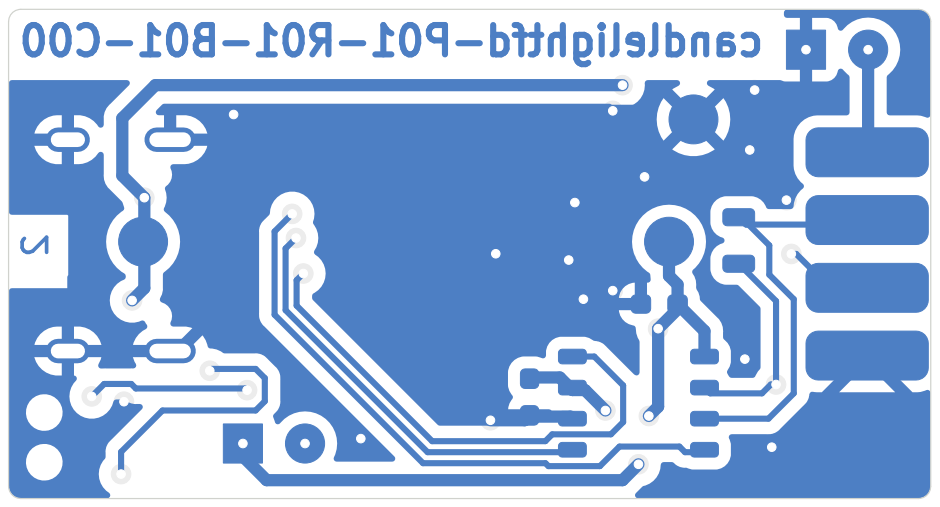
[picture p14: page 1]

git: hardware/candlelightfd-S01_candlelightfd State:release
Date:2022-03-07

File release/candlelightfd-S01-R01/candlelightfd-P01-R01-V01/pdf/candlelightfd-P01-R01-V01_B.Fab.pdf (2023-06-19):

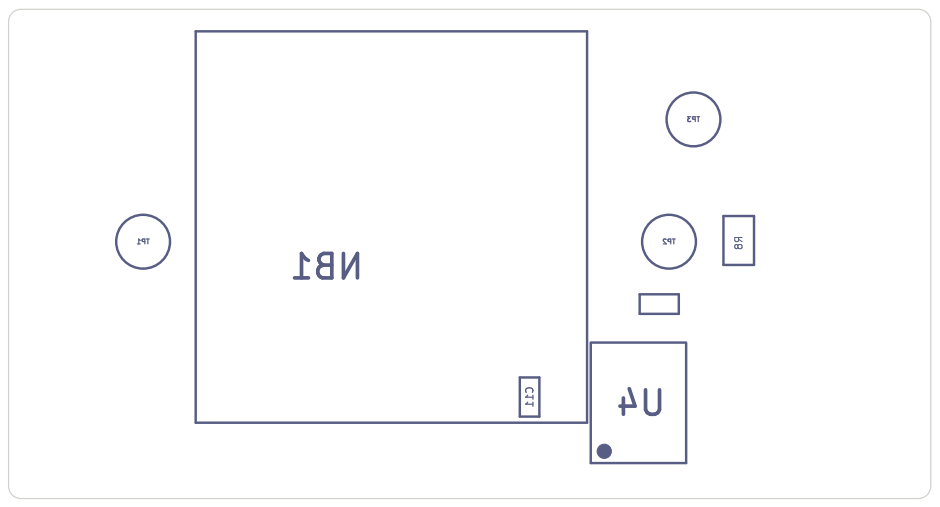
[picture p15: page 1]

git: hardware/candlelightfd-S01_candlelightfd State:release
Date:2022-03-07

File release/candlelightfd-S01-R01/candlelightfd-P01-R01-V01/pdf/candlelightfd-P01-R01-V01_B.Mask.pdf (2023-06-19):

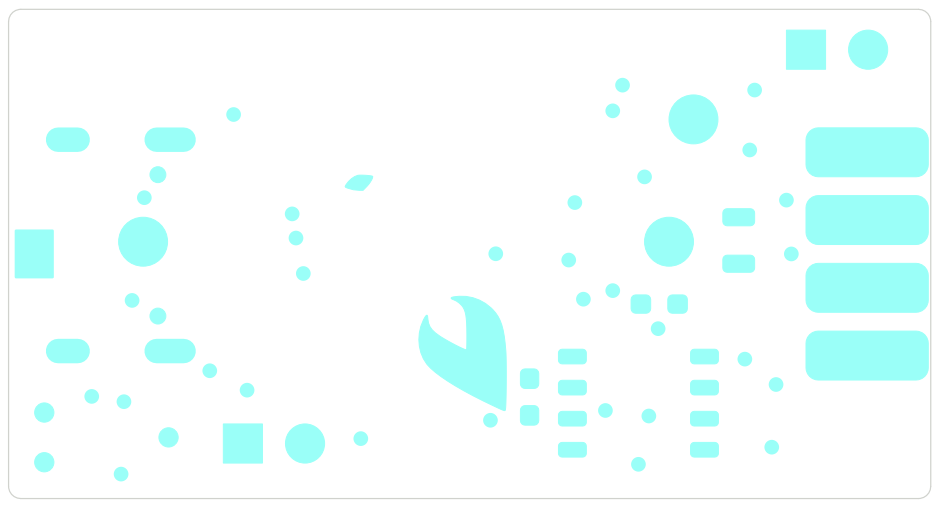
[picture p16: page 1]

git: hardware/candlelightfd-S01_candlelightfd State:release
Date:2022-03-07

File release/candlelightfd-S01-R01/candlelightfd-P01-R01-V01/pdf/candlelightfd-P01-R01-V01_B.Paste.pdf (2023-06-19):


git: hardware/candlelightfd-S01_candlelightfd State:release
Date:2022-03-07

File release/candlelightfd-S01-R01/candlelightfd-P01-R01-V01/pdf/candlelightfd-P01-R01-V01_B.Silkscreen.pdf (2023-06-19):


git: hardware/candlelightfd-S01_candlelightfd State:release
Date:2022-03-07

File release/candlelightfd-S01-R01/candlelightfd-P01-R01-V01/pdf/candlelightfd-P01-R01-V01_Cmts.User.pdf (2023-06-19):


git: hardware/candlelightfd-S01_candlelightfd State:release
Date:2022-03-07

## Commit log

2022-03-08 Add more fields, add some info-text to sch and pcb
    [lag-gitlab.kicad_pcb, lag-gitlab.kicad_sch]
2023-01-25 Fix titel block variable
    [lag-gitlab.kicad_sch]
2023-02-03 Begin project
    [candlelight-S02.kicad_pcb, candlelight-S02.kicad_sch, lag-gitlab.kicad_sch]
2023-02-08 Rename and add MCU place holder
    [MCU.kicad_sch, PSU.kicad_sch, candleLightfd-S01.kicad_pcb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]
2023-03-08 update kicad, add power flags
    [MCU.kicad_sch, PSU.kicad_sch, candleLightfd-S01.kicad_sch]
2023-05-04 Added all parts
    [MCU.kicad_sch, PSU.kicad_sch, candleLightfd-S01.kicad_pcb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]
2023-05-09 Placement nearly final
    [MCU.kicad_sch, PSU.kicad_sch, candleLightfd-S01.kicad_pcb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]
2023-05-09 Update kicad lib
    [MCU.kicad_sch, PSU.kicad_sch, candleLightfd-S01.kicad_pcb]
2023-05-15 Fin rounting
    [MCU.kicad_sch, PSU.kicad_sch, candleLightfd-S01.kicad_sch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]
2023-06-06 Save after recover
    [MCU.kicad_sch, PSU.kicad_sch, candleLightfd-S01.kicad_pcb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]
2023-06-06 Move kicad-ptx-lib to master
    [PSU.kicad_sch, candleLightfd-S01.kicad_pcb]
2023-06-06 Add 2mm test points, untent via
    [PSU.kicad_sch, candleLightfd-S01.kicad_pcb]
2023-06-16 Changes during review
    [MCU.kicad_sch, PSU.kicad_sch, candleLightfd-S01.kicad_pcb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]
2023-06-19 post review fix
    [MCU.kicad_sch, candleLightfd-S01.kicad_pcb]
2023-06-19 Create release R01
    [back-only-bom.csv, candleLightfd-S01.kicad_pcb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]
2023-06-23 Create 3x3 Panel
    The following changes have been done to the PCB:
    * Copper fill reduced to PCB size
    * Remove "P1" from Silk
    * Added Tab positions
    [candleLightfd-S01.kicad_pcb, candleLightfd-S01.kicad_sch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]
2023-07-31 Update lib, Fix wrong value in Crystal symbol
    [MCU.kicad_sch]
2023-08-15 transceiver.kicad_sch: Fix Typo
    [candleLightfd-S01.kicad_pcb, candleLightfd-S01.kicad_sch, transceiver.kicad_sch]
